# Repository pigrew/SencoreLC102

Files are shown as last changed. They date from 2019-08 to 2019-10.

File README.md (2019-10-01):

# Sencore LC102 Reverse-Engineering

## Firmware

The firmware is stored on an EEPROM. The circuit is designed to only read half of the
ROM, so half of the ROM binary is blank.

It uses a TMP80C39AP processor, part of the Intel MC-48 family. Its ROM is segmented
into four parts (the address bus is only as wide as 1/8th of the EEPROM). It can
toggle output ports in order to switch between I/O segments.

It has been disassembled using the xdasmx software (sadly, not open source), and
also a python script that will merge comments into the disassembly. I've mostly
been working on the "B" part, which handles GPIB.

If browsing the code, you should look at comments in the *.sym files, in adition to 
the *.lsta (annotated source listing) files.

## GPIB/RS232

Stored in firmware part B is the GPIB/RS232 controller logic. It uses an TMP82C43P to
expand its I/O ports and access a GPIB controller IC or UART. Here is the pin mapping that
I've figured out so far:

(From the point of view of LC102. Write goes to IB, Read comes from IB)

| Pin | Function |
|---|---|
| p4.\[3210\]  | D3 .. D0 |
| p5.\[3210\]  | D7 .. D4 |
|------------|----------|
| p6 | Inputs to the 8039 |
| p6.3 | Write ACK (active low) |
| p6.2 | Talk request, (only sent in write mode (P7.0=1)?), clear |
| p6.1 | (Normally low, is this a reset thing?) |
| p6.0 | READ data Available (active low), data already on P4/P5 bus. |
|------------|----------|
| p7 | Outputs from the 8039 |
| p7.3 | |
| p7.2 | W̅R̅I̅T̅E̅  |
| p7.1 | Read complete (active low) |
| p7.0 | Enter LC102 read phase (active low) |

(Below is from the point of view of the meter, not the IB slave)

To initialize:
1. Set p4,p5,p6,p7 to be read ports
2. p7 = 1110 (enter read phase)

To check if I should talk:
1. p7 = 1111
2. Abort if p6.2 is high.
3. Continue with write if p6.2 is low.

To write:

1. Put data on P4/P5 bus
2. Assert p7.2 low
3. Wait until p6.3 goes low (ACK) (p6.2 should go back high at this point, too)
4. Reset p7.2 high

To enter read phase:
1. Set p4/p5/p6 to inputs
2. P7 = 1111
3. p7 = 1110 (Sets read mode)

To perform read:
1. Wait until p6.0 goes low
2. Read data
3. Ack data by asserting p7.1 low
4. Wait until p6.0 goes high
5. Reset p7.1 high

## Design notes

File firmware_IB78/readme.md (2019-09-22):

Firmware for IB78 UART adapter.

|Component| Manufacturer | Part Number |
|---|---|---|
|Micro | Intel |P80C31BH  |
|EPROM |S |27C256-20 FA |
|IO Expander | NEC | D8243C |
|UART | National | NS8250AN/INS8250AN |

Memory map:

| Address | Content |
| --- | --- |
| 0x08 | Baud rate (indexed)
| 0x22 | global status register (bitfield)|
| 0x7fef | Peripheral (only reads), maybe the DIP switches?|
| 0x7ff7 | Peripheral (reads and writes) |
| 0x7ff8 | UART TX/RX data & divisor (muxed by DLAB) |
| 0x7ff9 | UART INT_EN table |
| 0x7ffa | UART INT_FLAG table |
| 0x7ffb | UART line control (parity, stop bits, etc) |
| 0x7ffc | UART modem control |
| 0x7ffd | UART line status |
| 0x7ffe | UART modem status |

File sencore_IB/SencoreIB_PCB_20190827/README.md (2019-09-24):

# Sencore-IB to USB PCB

This is an Altium-based PCB project for a Sencore-IB to USB clone.

# Defects

Some defects have been noticed on this PCB revision:

1. The selected isolated DC-DC converter is unregulated. This would fry the bus tranceiver IC. Correct by cutting the track at the input of the bus tranceiver IC and add a TPS77050 LDO.
2. Some silkscreens are not in the proper place. A lot of the pin-1 designators didn't make it.
3. The selected STM32F042 barely has enough RAM to run the USB stack. Board revisions need a different footprint to accept MCUs with more RAM. For the current footprint, STM32F070F6P6TR could be used which has more flash, but not more RAM (and it needs an external crystal).
4. USB D+ and D- are swapped; Do a crossover in place of R17/R18.
5. Pinout of U3 is flipped; Mount part upsidedown, but leave the pin closest to the RS232 connector up in the air (the flag pin).
6. JTAG pins are connected to the wrong place. SWDIO should be pin13, SWCLK should be pin14

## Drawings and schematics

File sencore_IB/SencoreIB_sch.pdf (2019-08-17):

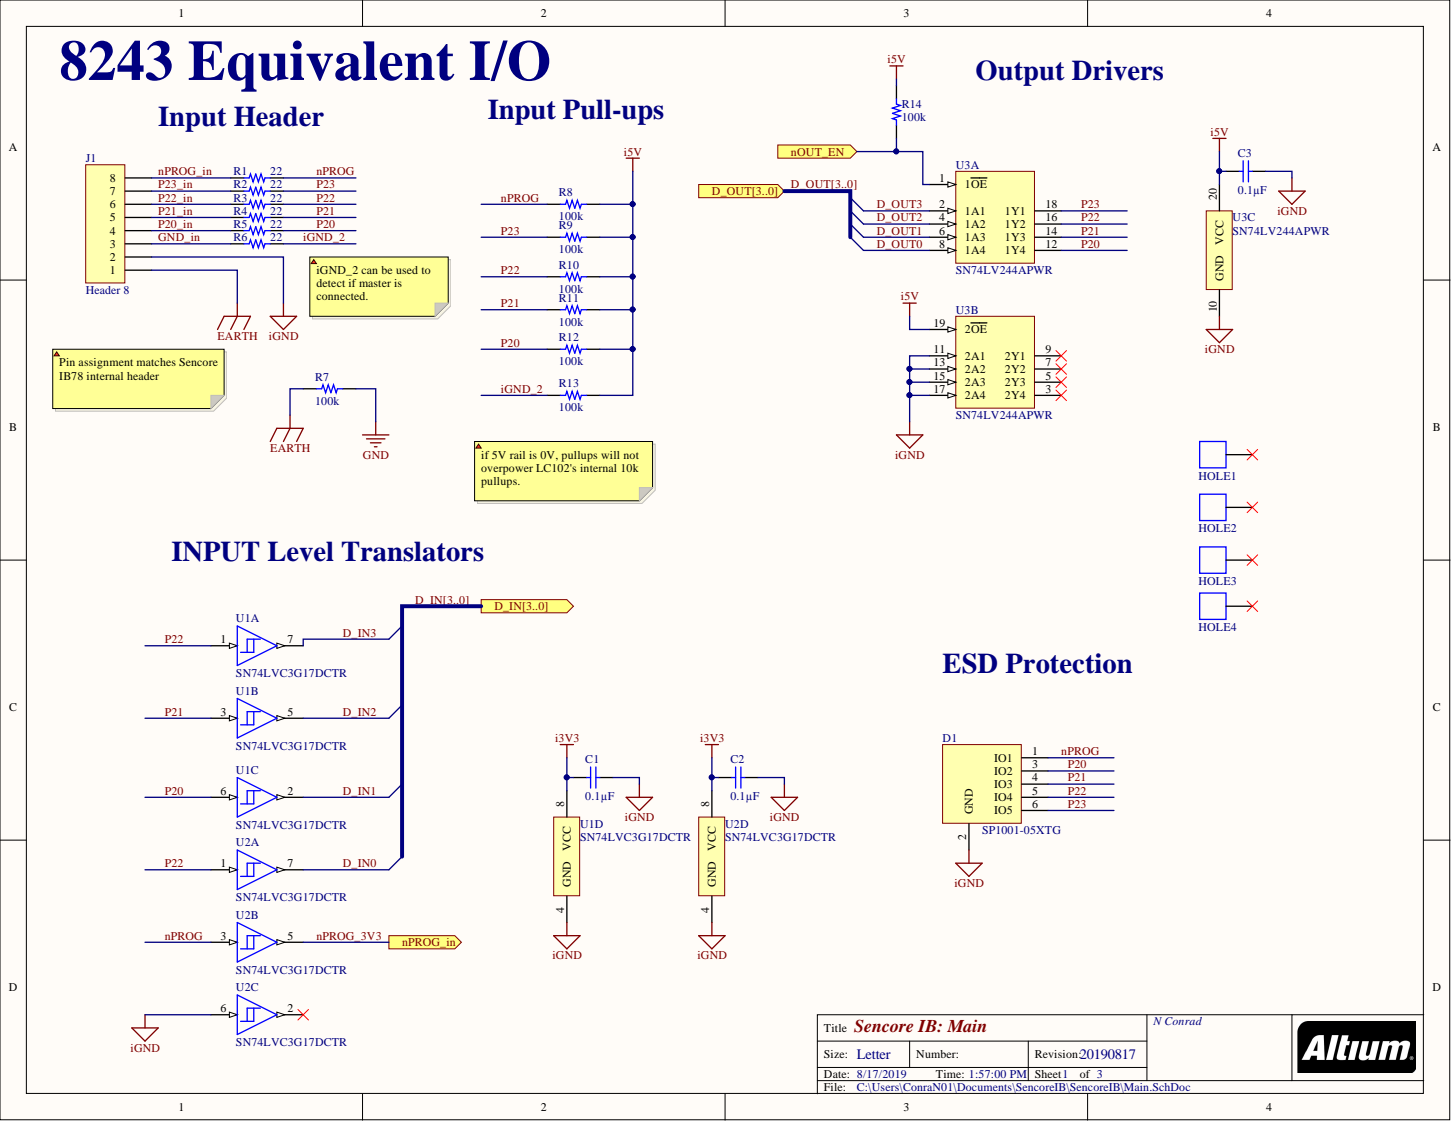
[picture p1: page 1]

iGND_2 can be used to
detect if master is
connected.

Pin assignment matches Sencore
IB78 internal header

if 5V rail is 0V, pullups will not
overpower LC102's internal 10k
pullups.

Sencore IB: Main Title | N Conrad

Size: Letter | Number: | Revision:
Date: 8/17/2019 Time: 1:57:00 PM | | Sheet of

C:\Users\ConraN01\Documents\SencoreIB\SencoreIB\Main.SchDoc

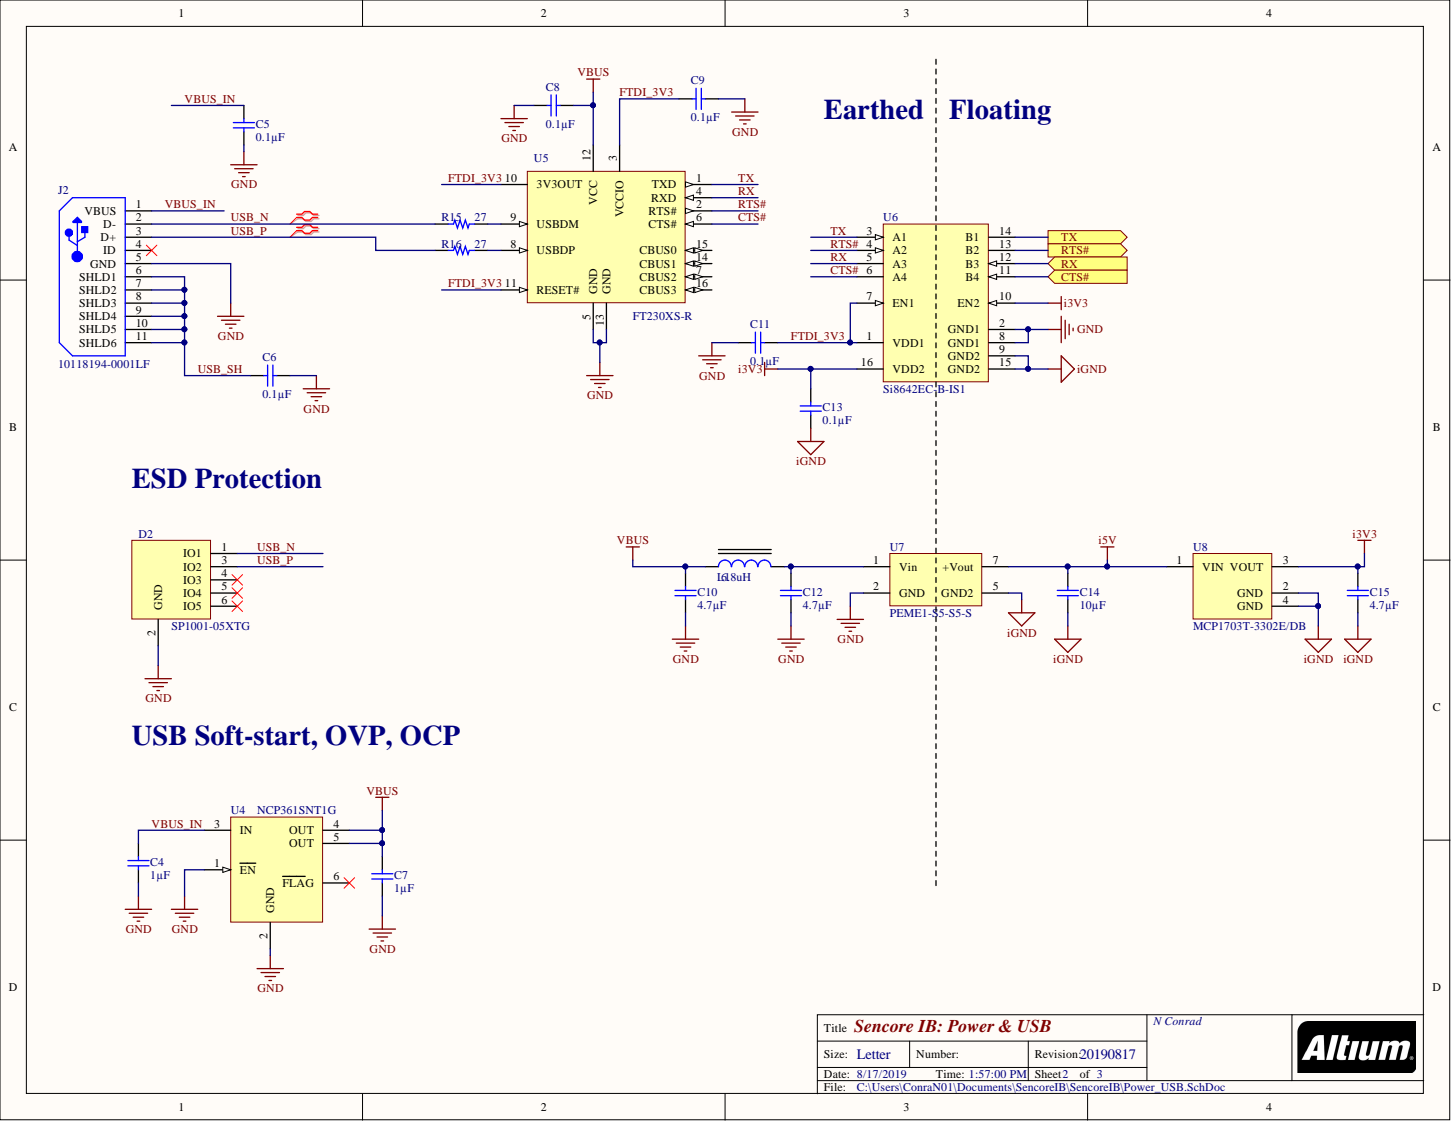
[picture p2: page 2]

GND
USB Soft-start, OVP, OCP

Sencore IB: Power & USB

C:\Users\ConraN01\Documents\SencoreIB\SencoreIB\Power_USB.SchDoc

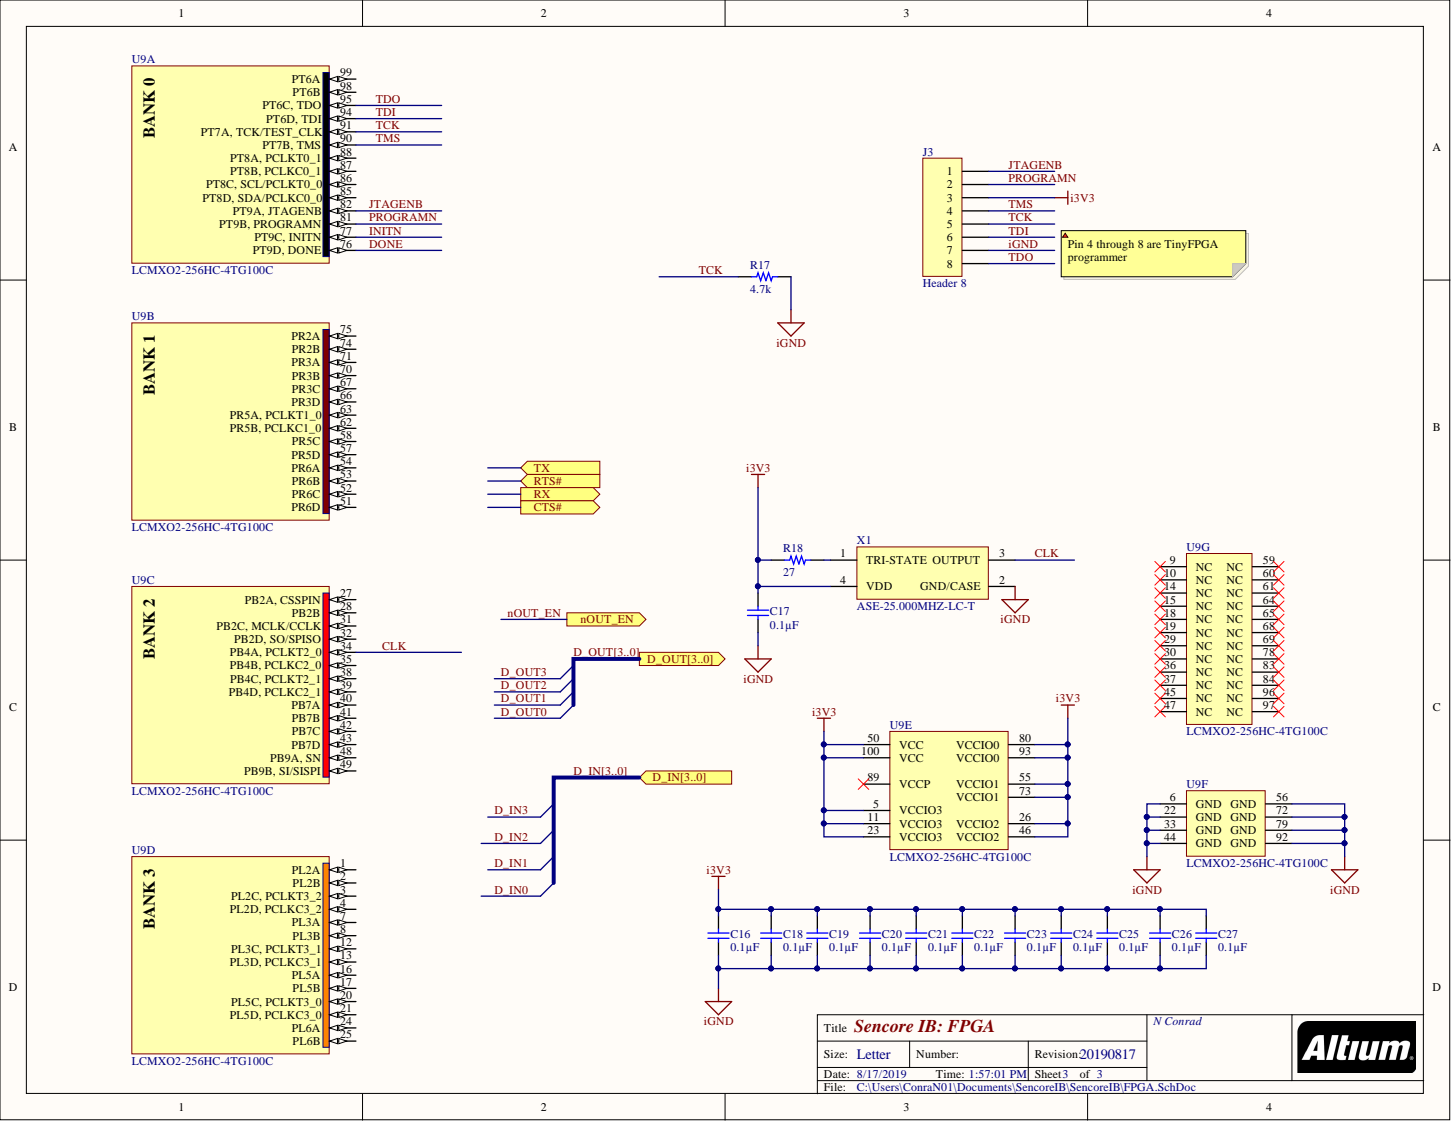
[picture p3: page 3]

Pin 4 through 8 are TinyFPGA
programmer

C:\Users\ConraN01\Documents\SencoreIB\SencoreIB\FPGA.SchDoc

Line # | Description | Designator | Q uantity | TargetPrice | Manufacturer1 | ManufacturerPart Number1 | Supplier 1 | SupplierPart Number1 | Supplier Unit Price 1 | SupplierSubtotal 1
1 | C A P C ER 0.1UF 50V X7R 0603 | C 1-C 3,C 5,C 6, | 21 | 0.21 | Murata | GC J188R71H104KA12D | Digi-Key | 490-5798-1-ND | 0.21 | 4.41
2 | C A P C ER 1UF 25V X7R 0603 | C 4,C7 | 2 | 0.31 | Murata | GC M188R71E105KA64D | Digi-Key | 490-10673-1-ND | 0.31 | 0.62
3 | C A P C ER 4.7UF 25V X7S 0805 | C 10,C 12,C15 | 3 | 0.49 | Murata | GC M21BC 71E475KE36L | Digi-Key | 490-14435-1-ND | 0.49 | 1.47
4 | C A P C ER 10UF 10V X7R 0805 | C14 | 1 | 0.62 | Murata | GC M21BR71A106KE22K | Digi-Key | 490-14531-1-ND | 0.62 | 0.62
5 | TV S DIO DE 5.5VWM 13VC SOT563 | D1,D2 | 2 | 0.6 | Littelfuse | SP1001-05XTG | Digi-Key | F 2898CT-ND | 0.6 | 1.2
6 | Header, 8-Pin | J1, J3 | 2 | 0
7 | MicroUSB B Ty peReceptacle, 1.8 A ,-55 toJ 2 | | 1 | 0.42 | A mphenol FCI | 10118194-0001LF | Digi-Key | 609-4618-6-ND | 0.42 | 0.42
8 | F IXED IND 6.8UH 1.45A 117.6 MOHM | L1 | 1 | 0.29 | TaiyoYuden | NRS4018T6R8MDGJ | Digi-Key | 587-2894-1-ND | 0.29 | 0.29
9 | RES SMD 22 O HM 5% 1/10W0603 | R1-R6 | 6 | 0.02 | Yageo | RC 0603JR-0722RL | Digi-Key | 311-22GRCT-ND | 0.02 | 0.2
10 | RES SMD 100KO HM 5% 1/10W0603 | R7-R14 | 8 | 0.02 | Yageo | RC 0603JR-07100KL | Digi-Key | 311-100KGRCT-ND | 0.02 | 0.2
11 | RES SMD 27 O HM 5% 1/10W0603 | R15,R16,R18 | 3 | 0.02 | Yageo | RC 0603JR-0727RL | Digi-Key | 311-27GRCT-ND | 0.02 | 0.2
12 | RES SMD 4.7K O HM 5% 1/10W0603 | R17 | 1 | 0.1 | Yageo | RC 0603JR-074K7L | Digi-Key | 311-4.7KGRCT-ND | 0.1 | 0.1
13 | TRIPLE SC HMITT-TRIGGERBUFFER,DCU1, U2 | | 2 | 0.69 | Texas InstrumentsSN74LVC3G17DCTR | | Mouser | 595-SN74LVC3G17DCTR | 0.69 | 1.38
14 | O ctal Buffers/Drivers With 3-StateO utputs,U3 | | 1 | 0.46546 | Texas InstrumentsSN74LV 244APWR | | F arnell | 1619139 | 0.46546 | 0.46546
15 | IC USB POS OVP/OCP 5TSOP | U4 | 1 | 0.73 | O N SemiconductorNC P361SNT1G | | Digi-Key | NC P361SNT1GOSCT-ND | 0.73 | 0.73
16 | USB toBasicUA RT InterfaceC hip,UHC I/U5 | | 1 | 1.96 | FTDI | FT230X S- R | F arne ll | 2081321 | 1.96 | 1.96
17 | Low-PowerQ uad-C hannel Digital IsolatorU 6 | | 1 | 3.09 | Silico n Labs | S I8642E C-B-IS1 | Digi-Key | 336-2094-5-ND | 3.09 | 3.09
18 | 5 V dc, 0.2 A , 1 W, 4.5 ~ 5.5 V dc Input Ra U7 | | 1 | 0.29 | TaiyoYuden | NRS4018T6R8MDGJ | Digi-Key | 587-2894-1-ND | 0.29 | 0.29
19 | 250 mA , 16V, Low Q uiescent C urrent LDO U8 | | 1 | 0.64 | Micr ochip | MC P1703T-3302E/DB | Digi-Key | MC P1703T-3302E/DBDKR | 0.64 | 0.64
20 | MachXO 2 High PerformanceC PLD with 256 U9 | | 1 | 4. 29 | L atticeSem iconduc LCMXO2-256HC-4TG1 00C | | Mouse r | 842-2256HC4TG100C | 4.29 | 4.29
21 | C MO S C ry stal O scillatorl,3.3 V , 25 MHz,+X1 | | 1 | 1.09 | Abracon | A SE-25.000MHZ-LC-T | Newark | 84R2104 | 1.09 | 1.09

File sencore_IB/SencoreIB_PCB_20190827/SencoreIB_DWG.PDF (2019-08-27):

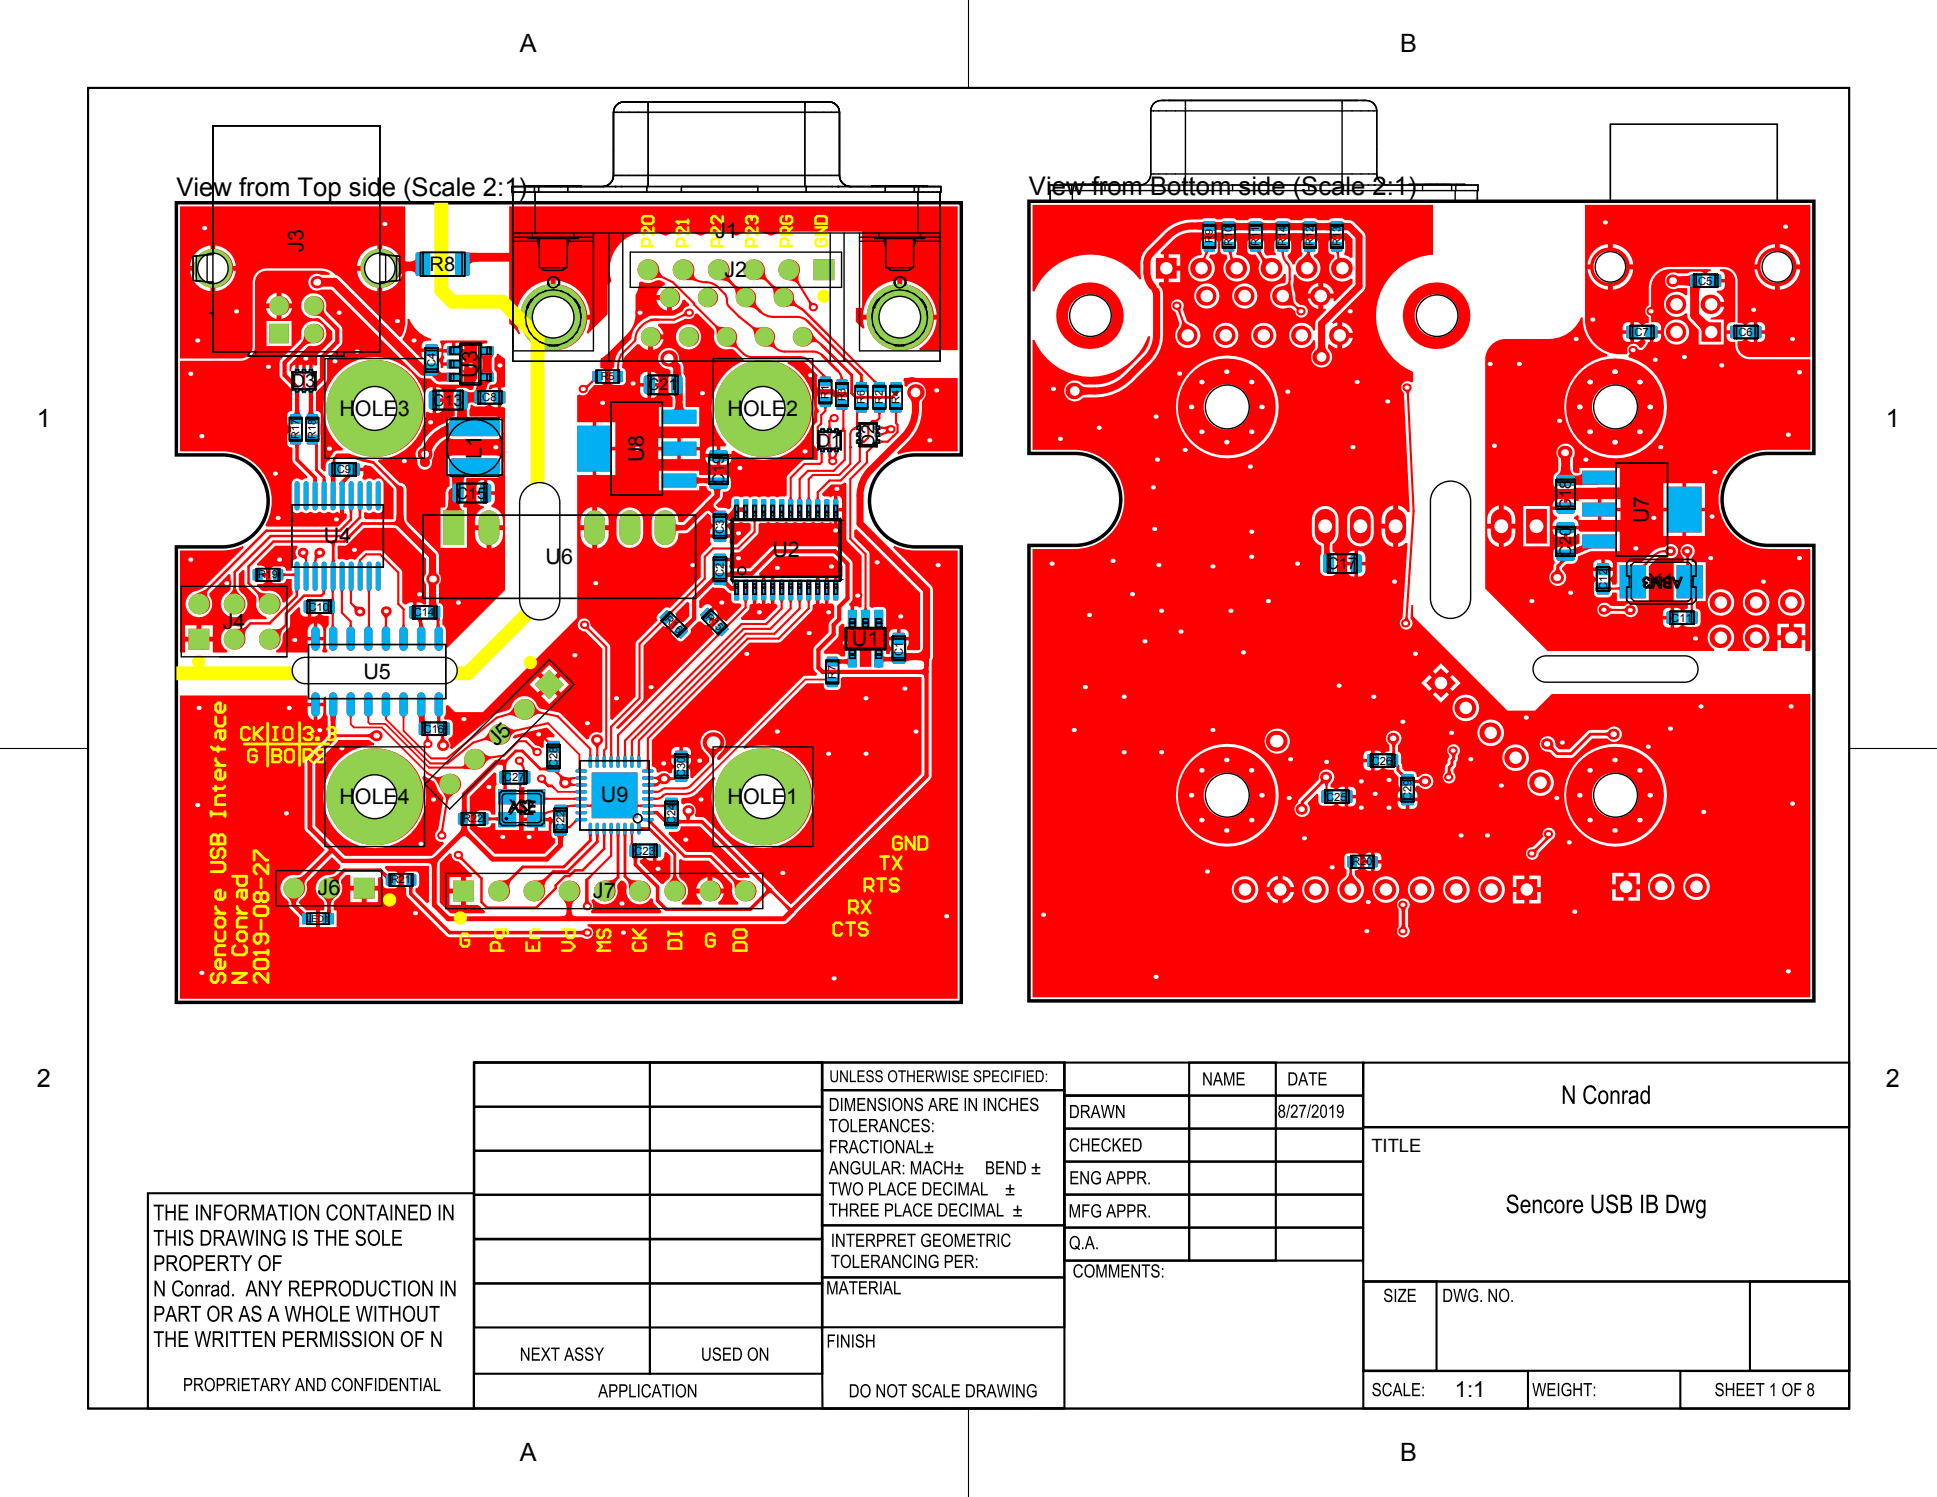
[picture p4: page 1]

View from Top side (Scale 2:1)

View from Bottom side (Scale 2:1)

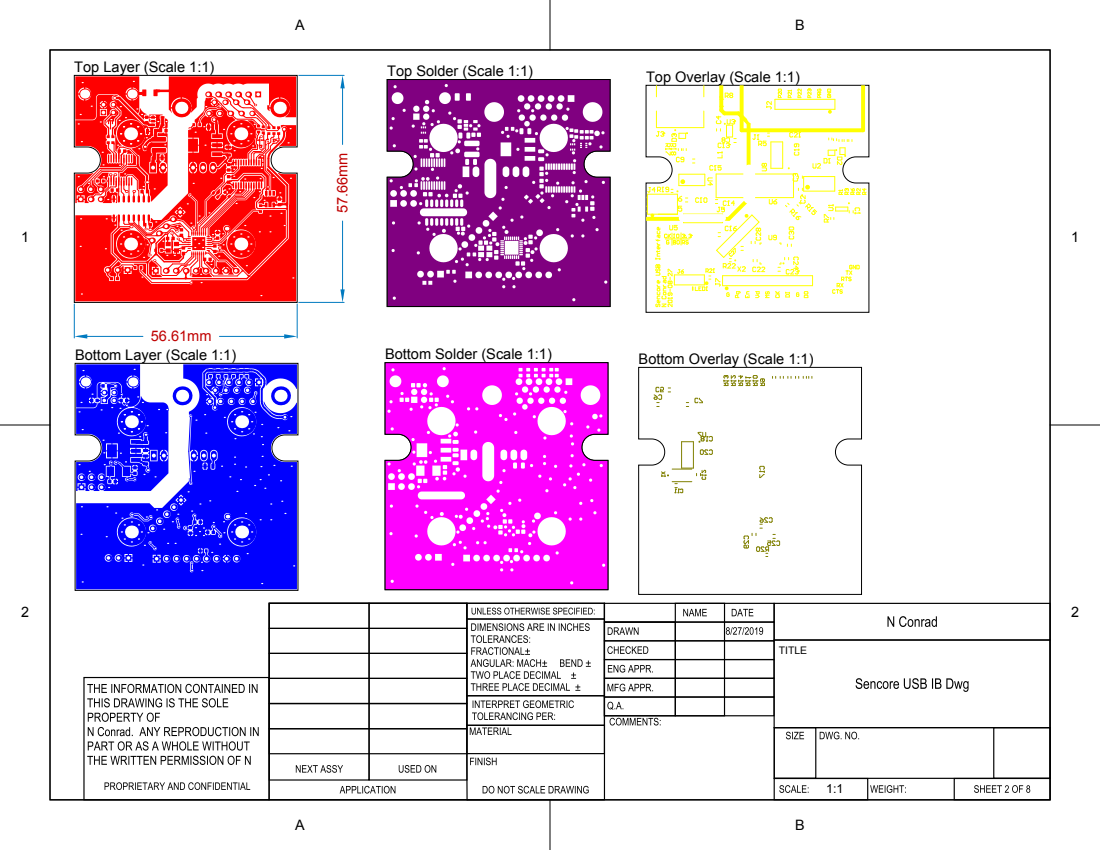
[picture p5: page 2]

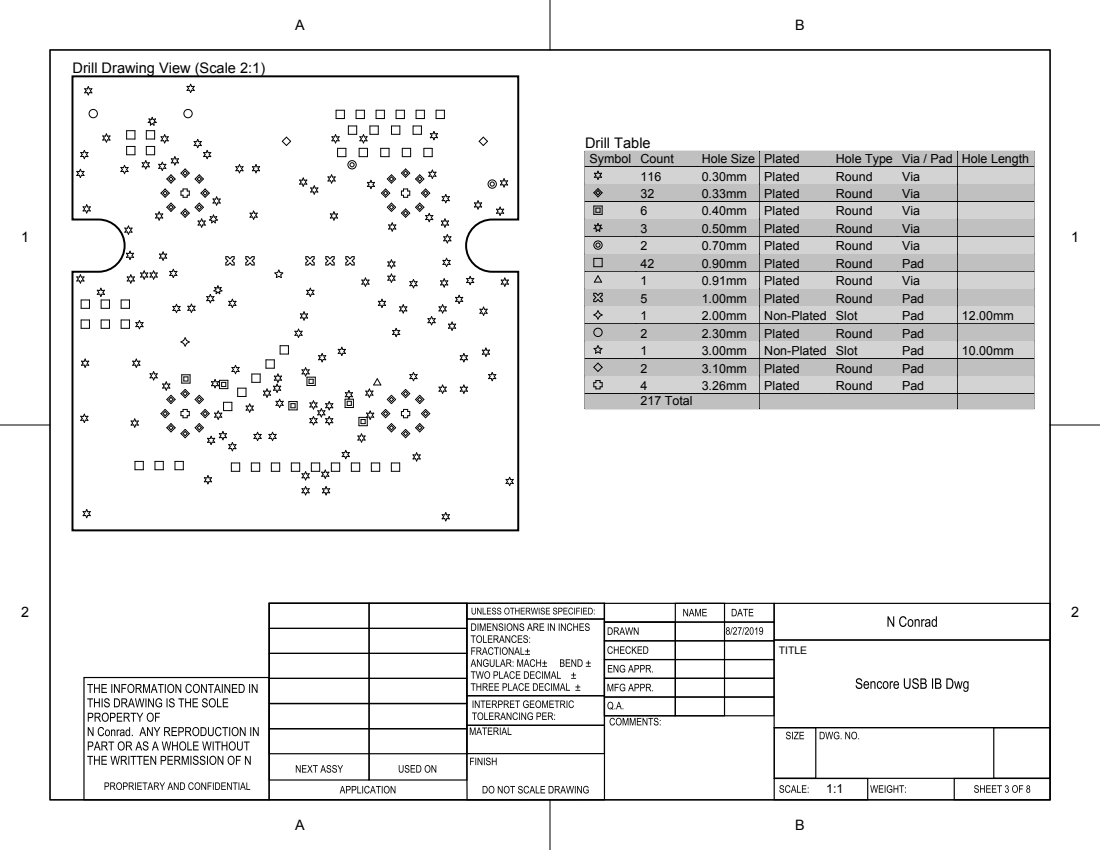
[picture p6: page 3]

Drill Drawing View (Scale 2:1)

Symbol | Count | Hole Size | Plated | Hole Type | Via / Pad | Hole Length

116 | 0.30mm | Plated | Round | Via
32 | 0.33mm | Plated | Round | Via
6 | 0.40mm | Plated | Round | Via
3 | 0.50mm | Plated | Round | Via
2 | 0.70mm | Plated | Round | Via
42 | 0.90mm | Plated | Round | Pad
1 | 0.91mm | Plated | Round | Via
5 | 1.00mm | Plated | Round | Pad
1 | 2.00mm | Non-Plated | Slot | Pad | 12.00mm
2 | 2.30mm | Plated | Round | Pad
1 | 3.00mm | Non-Plated | Slot | Pad | 10.00mm
2 | 3.10mm | Plated | Round | Pad
4 | 3.26mm | Plated | Round | Pad
217 Total

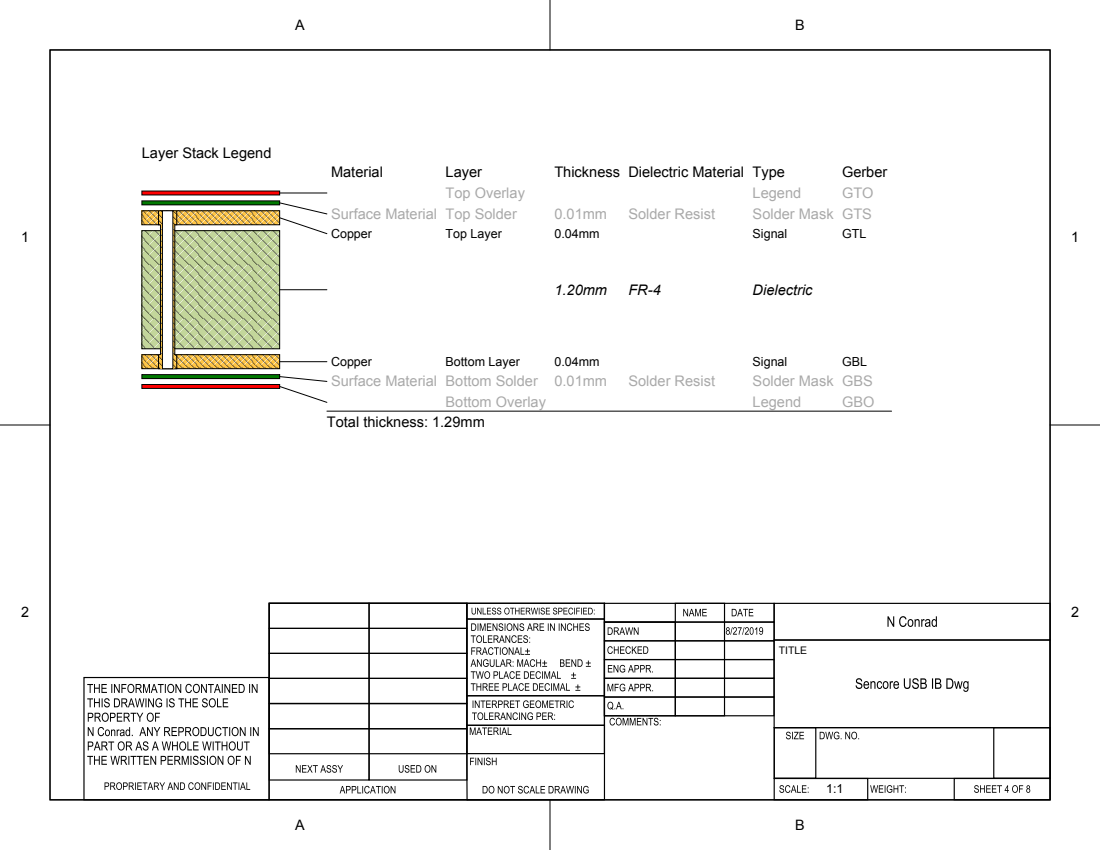
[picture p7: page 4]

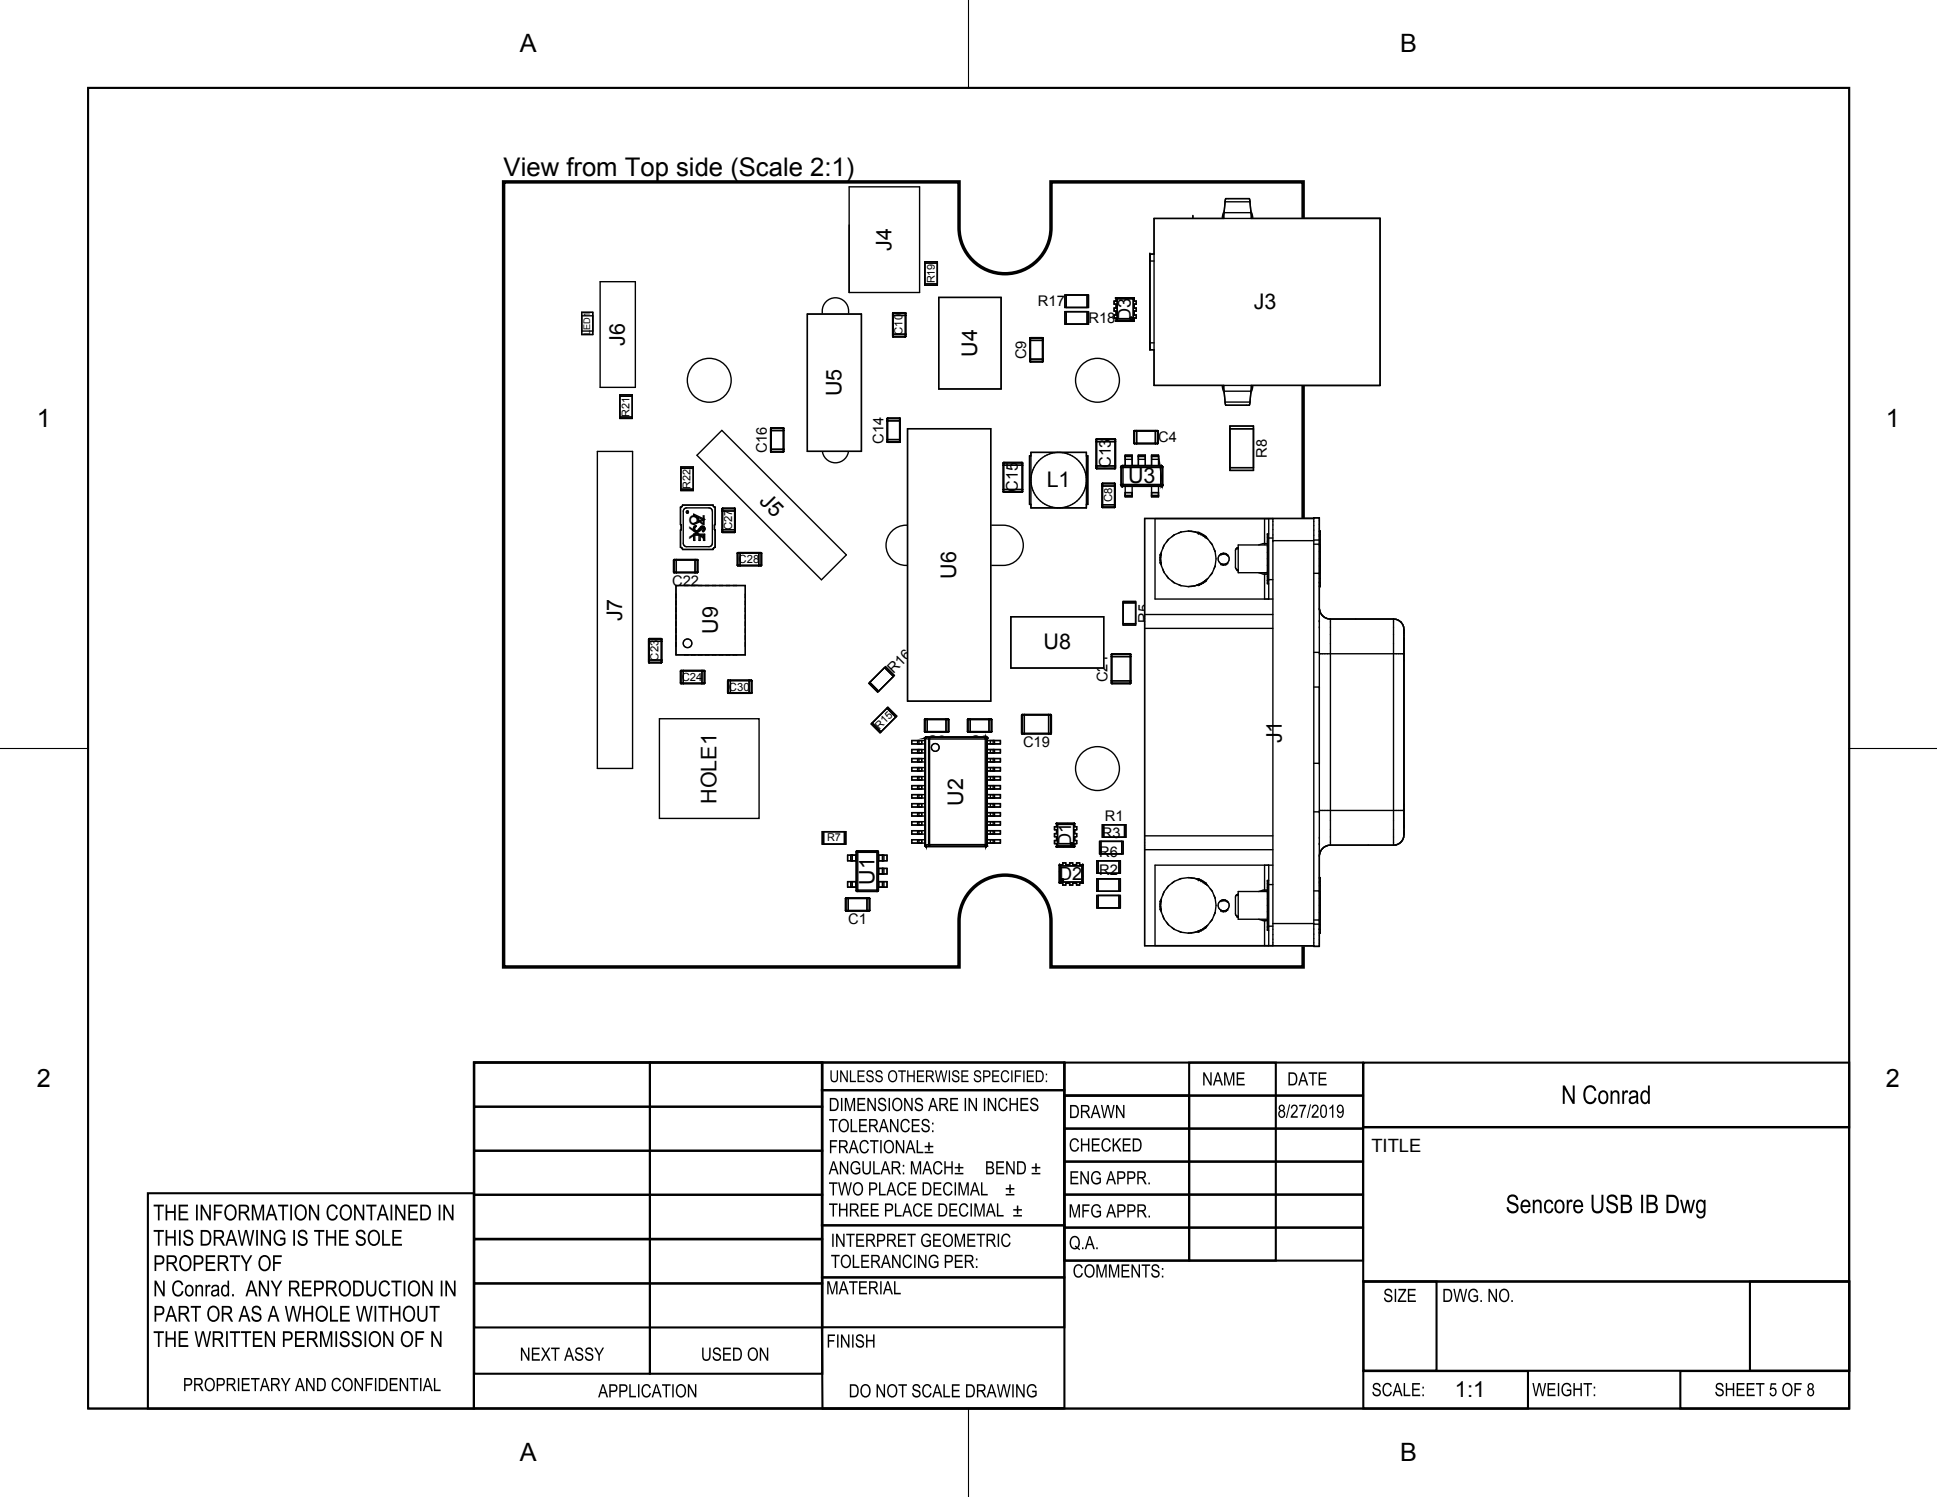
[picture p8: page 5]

View from Top side (Scale 2:1)

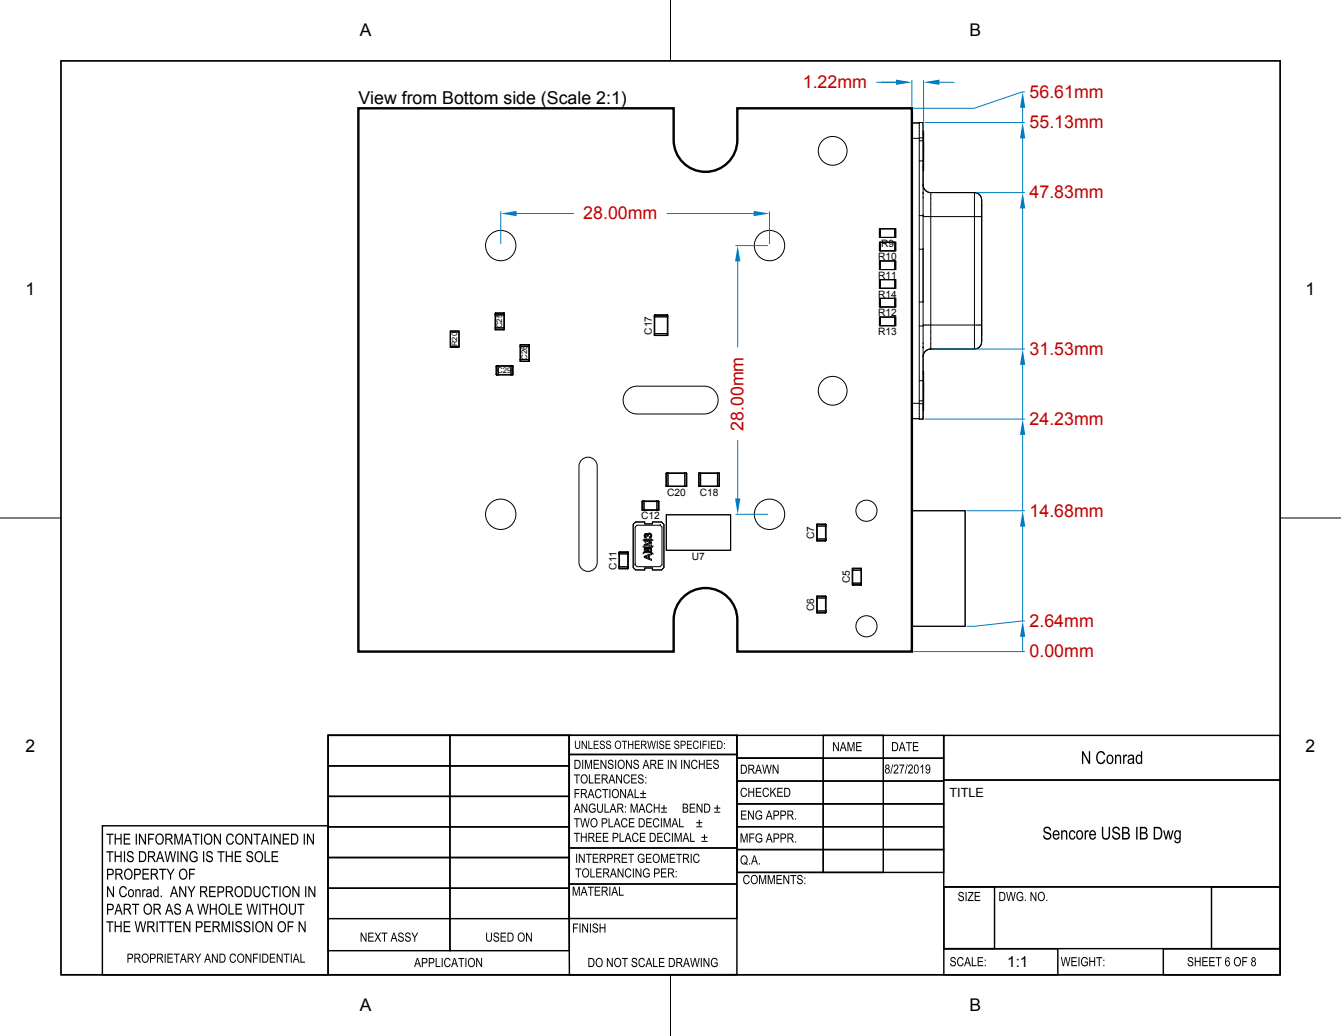
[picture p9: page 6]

View from Bottom side (Scale 2:1)

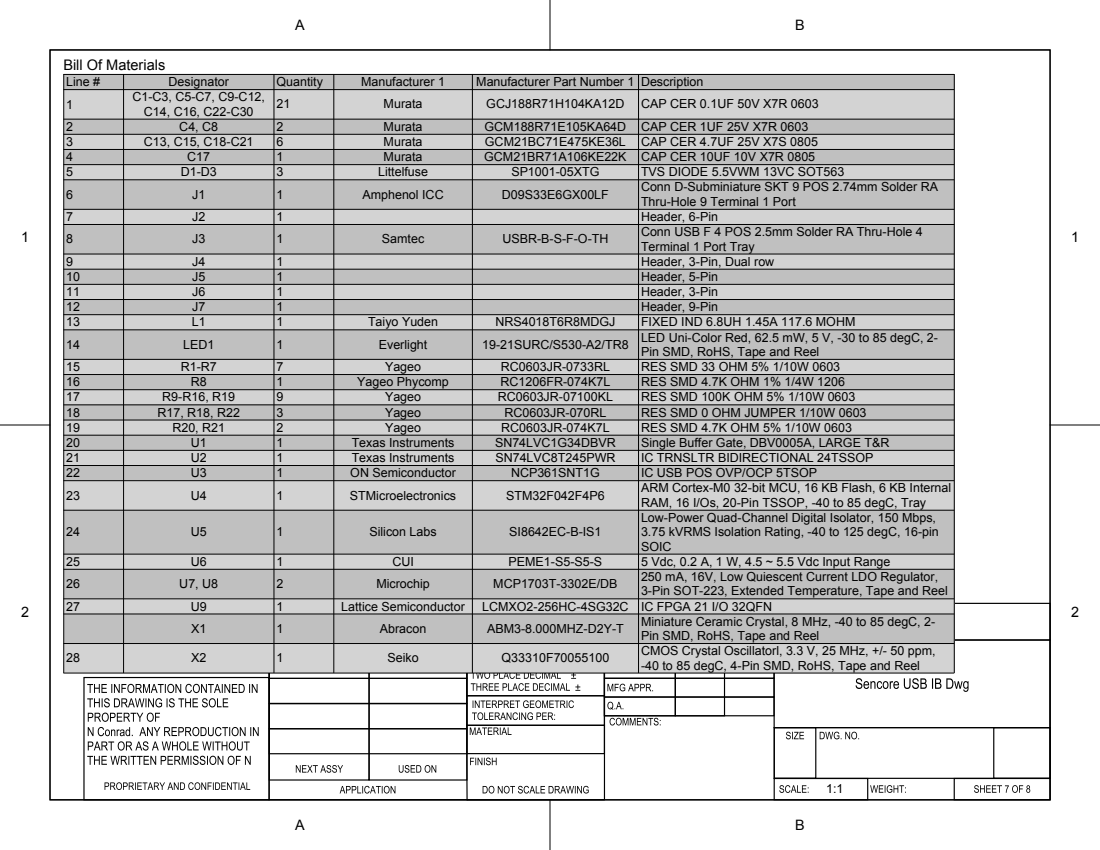
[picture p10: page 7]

Line # | Designator | Quantity | Manufacturer 1 | Manufacturer Part Number 1 | Description
1 | C1-C3, C5-C7, C9-C12, C14, C16, C22-C30 | 21 | Murata | GCJ188R71H104KA12D | CAP CER 0.1UF 50V X7R 0603

2 | C4, C8 | 2 | Murata | GCM188R71E105KA64D | CAP CER 1UF 25V X7R 0603
3 | C13, C15, C18-C21 | 6 | Murata | GCM21BC71E475KE36L | CAP CER 4.7UF 25V X7S 0805
4 | C17 | 1 | Murata | GCM21BR71A106KE22K | CAP CER 10UF 10V X7R 0805
5 | D1-D3 | 3 | Littelfuse | SP1001-05XTG | TVS DIODE 5.5VWM 13VC SOT563
6 | J1 | 1 | Amphenol ICC | D09S33E6GX00LF | Conn D-Subminiature SKT 9 POS 2.74mm Solder RA Thru-Hole 9 Terminal 1 Port

7 | J2 | 1 | | | Header, 6-Pin
8 | J3 | 1 | Samtec | USBR-B-S-F-O-TH | Conn USB F 4 POS 2.5mm Solder RA Thru-Hole 4 Terminal 1 Port Tray

9 | J4 | 1 | | | Header, 3-Pin, Dual row
10 | J5 | 1 | | | Header, 5-Pin
11 | J6 | 1 | | | Header, 3-Pin
12 | J7 | 1 | | | Header, 9-Pin
13 | L1 | 1 | Taiyo Yuden | NRS4018T6R8MDGJ | FIXED IND 6.8UH 1.45A 117.6 MOHM
14 | LED1 | 1 | Everlight | 19-21SURC/S530-A2/TR8 | LED Uni-Color Red, 62.5 mW, 5 V, -30 to 85 degC, 2-Pin SMD, RoHS, Tape and Reel

15 | R1-R7 | 7 | Yageo | RC0603JR-0733RL | RES SMD 33 OHM 5% 1/10W 0603
16 | R8 | 1 | Yageo Phycomp | RC1206FR-074K7L | RES SMD 4.7K OHM 1% 1/4W 1206
17 | R9-R16, R19 | 9 | Yageo | RC0603JR-07100KL | RES SMD 100K OHM 5% 1/10W 0603
18 | R17, R18, R22 | 3 | Yageo | RC0603JR-070RL | RES SMD 0 OHM JUMPER 1/10W 0603
19 | R20, R21 | 2 | Yageo | RC0603JR-074K7L | RES SMD 4.7K OHM 5% 1/10W 0603
20 | U1 | 1 | Texas Instruments | SN74LVC1G34DBVR | Single Buffer Gate, DBV0005A, LARGE T&R
21 | U2 | 1 | Texas Instruments | SN74LVC8T245PWR | IC TRNSLTR BIDIRECTIONAL 24TSSOP
22 | U3 | 1 | ON Semiconductor | NCP361SNT1G | IC USB POS OVP/OCP 5TSOP
23 | U4 | 1 | STMicroelectronics | STM32F042F4P6 | ARM Cortex-M0 32-bit MCU, 16 KB Flash, 6 KB Internal RAM, 16 I/Os, 20-Pin TSSOP, -40 to 85 degC, Tray

24 | U5 | 1 | Silicon Labs | SI8642EC-B-IS1 | Low-Power Quad-Channel Digital Isolator, 150 Mbps, 3.75 kVRMS Isolation Rating, -40 to 125 degC, 16-pin SOIC

25 | U6 | 1 | CUI | PEME1-S5-S5-S | 5 Vdc, 0.2 A, 1 W, 4.5 ~ 5.5 Vdc Input Range
26 | U7, U8 | 2 | Microchip | MCP1703T-3302E/DB | 250 mA, 16V, Low Quiescent Current LDO Regulator, 3-Pin SOT-223, Extended Temperature, Tape and Reel

1 | Lattice Semiconductor | | LCMXO2-256HC-4SG32C | | IC FPGA 21 I/O 32QFN

X1 | 1 | | Abracon | | Miniature Ceramic Crystal, 8 MHz, -40 to 85 degC, 2-

ABM3-8.000MHZ-D2Y-T | | Pin SMD, RoHS, Tape and Reel

28 | X2 | | Q33310F70055100 | CMOS Crystal Oscillatorl, 3.3 V, 25 MHz, +/- 50 ppm, -40 to 85 degC, 4-Pin SMD, RoHS, Tape and Reel | TITLE

1 | Seiko

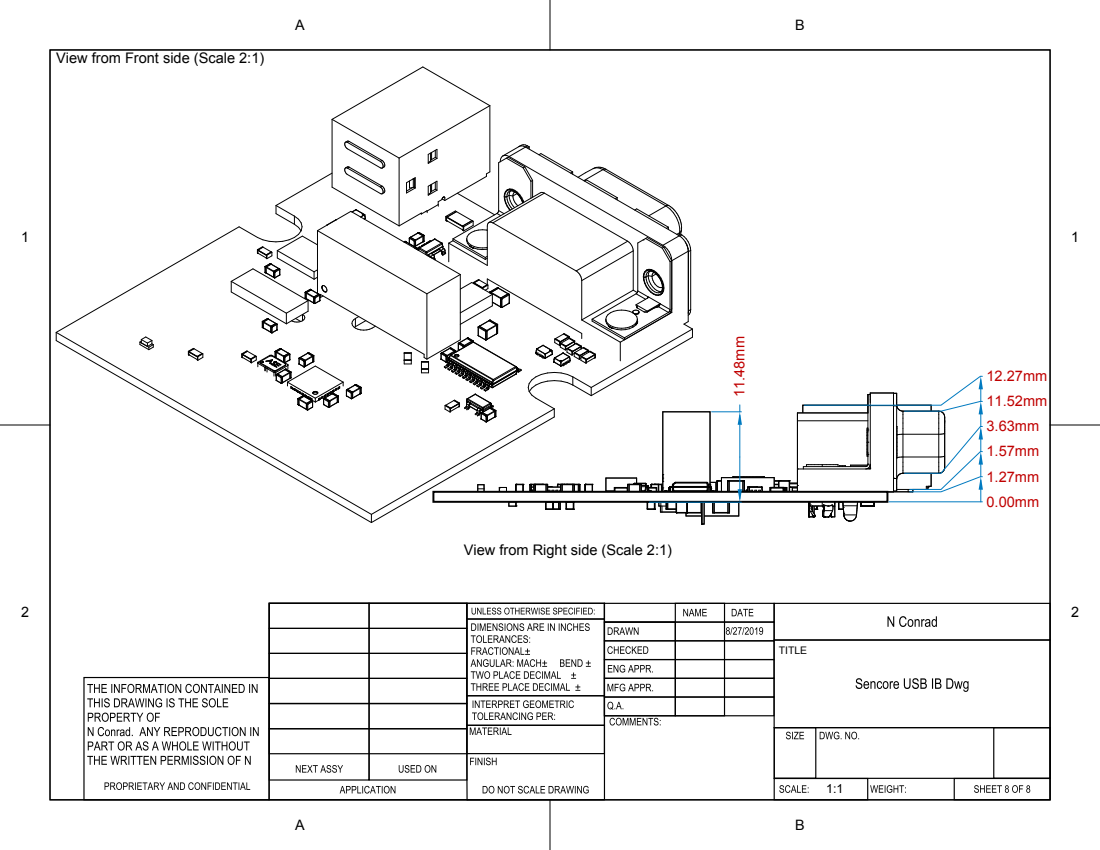
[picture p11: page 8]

View from Front side (Scale 2:1)

View from Right side (Scale 2:1)

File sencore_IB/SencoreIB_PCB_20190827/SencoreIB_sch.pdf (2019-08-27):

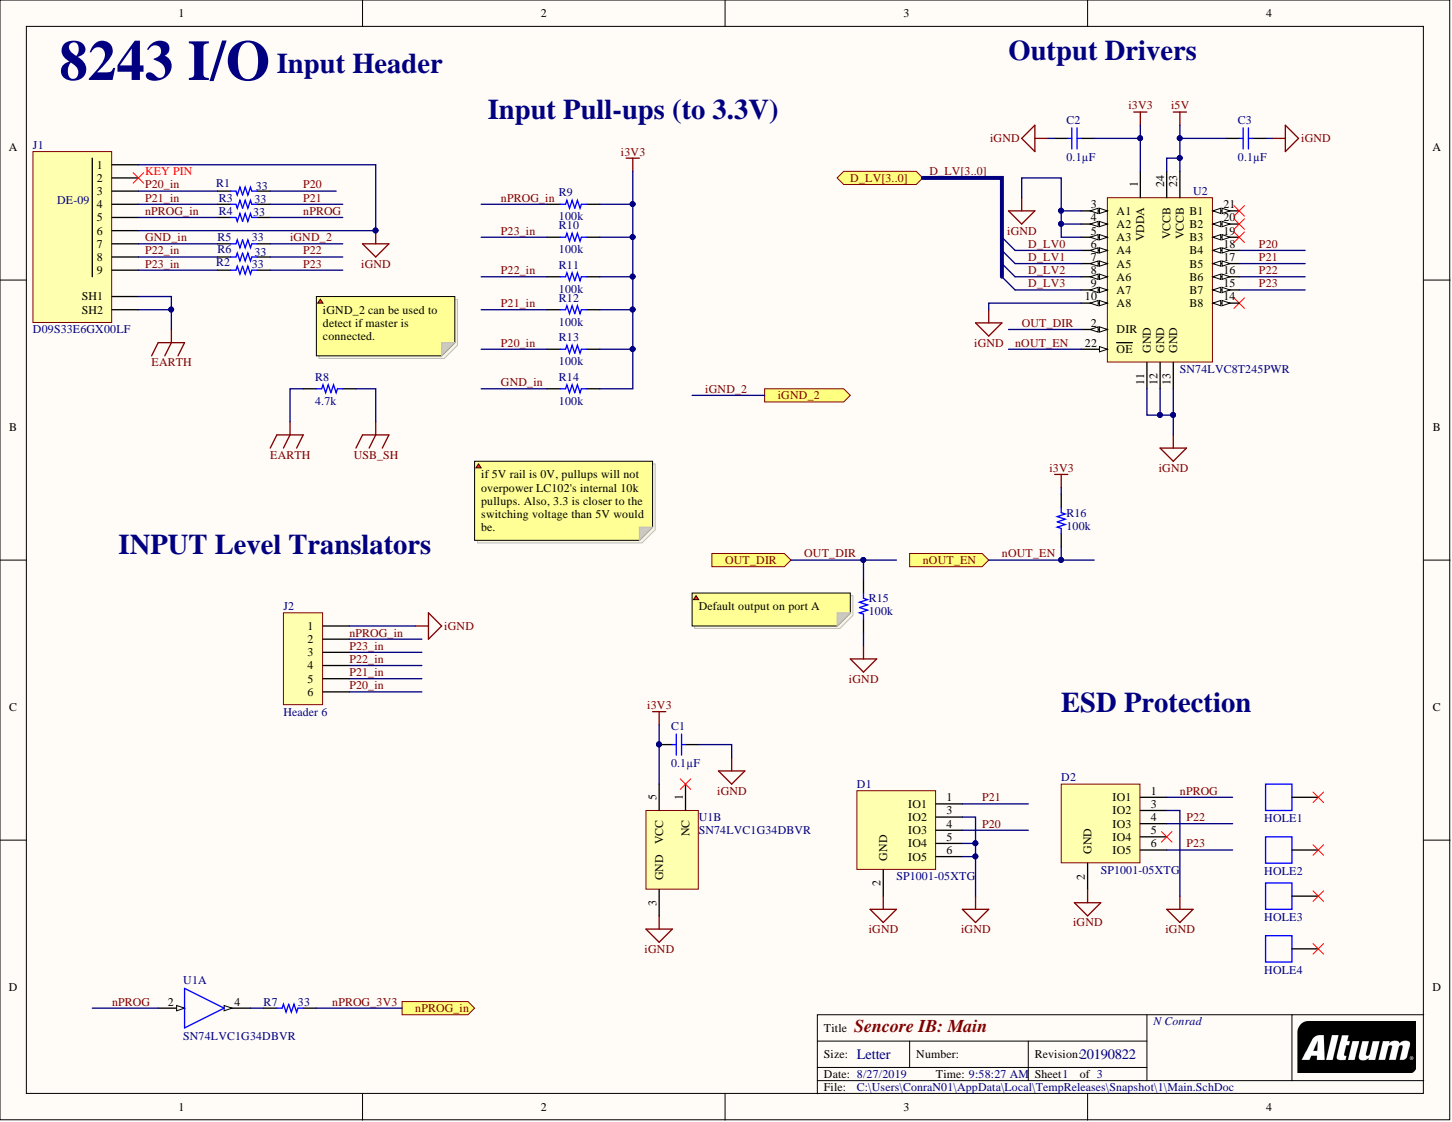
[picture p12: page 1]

Input Pull-ups (to 3.3V)

iGND_2 can be used to
detect if master is
connected.

if 5V rail is 0V, pullups will not
overpower LC102's internal 10k
pullups. Also, 3.3 is closer to the
switching voltage than 5V would

Default output on port A

Sencore IB: Main Title | N Conrad

Size: Letter | Number: | Revision:
Date: 8/27/2019 Time: 9:58:27 AM | | Sheet of

C:\Users\ConraN01\AppData\Local\TempReleases\Snapshot\1\Main.SchDoc


GND
USB Soft-start, OVP, OCP

Sencore IB: Power & USB | N Conrad

Letter

C:\Users\ConraN01\AppData\Local\TempReleases\Snapshot\1\Power_USB.SchDoc


DONE should be normally usable. Worst
case, it's open drain, so shouldn't
conflict...

Pin 5 through 9 are TinyFPGA
programmer "compatible"

C:\Users\ConraN01\AppData\Local\TempReleases\Snapshot\1\FPGA.SchDoc

Line # | Description | Designator | Q uantity | Manufacturer 1 | Manufacturer Part Number 1 | Supplier 1 | Supplier Part Number 1 | Supplier Unit Price 1 | Supplier Subtotal 1
1 | C A P C ER 0.1UF 50V X7R 0603 | C 1-C 3, C 5-C 7, C 9-C 12, C 14 | 21 | Murata | GC J188R71H104KA12D | Digi-Key | 490-5798-1-ND | 0.21 | 4.41
2 | C A P C ER 1UF 25V X7R 0603 | C 4, C8 | 2 | Murata | GC M188R71E105KA64D | Digi-Key | 490-10673-1-ND | 0.31 | 0.62
3 | C A P C ER 4.7UF 25V X7S 0805 | C 13, C 15, C 18-C21 | 6 | Murata | GC M21BC 71E475KE36L | Digi-Key | 490-14435-1-ND | 0.49 | 2.94
4 | C A P C ER 10UF 10V X7R 0805 | C17 | 1 | Murata | GC M21BR71A106KE22K | Digi-Key | 490-14531-1-ND | 0.62 | 0.62
5 | TV S DIO DE 5.5VWM 13VC SOT563 | D1-D3 | 3 | Littelfuse | SP1001-05XTG | Digi-Key | F 2898CT-ND | 0.6 | 1.8
6 | C onn D-Subminiature SKT 9 PO S 2.74mmJ1 | | 1 | A mphenol ICC | D09S33E6GX00LF | Digi-Key | 609-6160-ND | 1.43 | 1.43
7 | Header, 6-Pin | J2 | 1
8 | C onn USB F 4 PO S 2.5mm Solder RA ThrJ3 | | 1 | Samtec | USBR-B-S-F-O-TH | Digi-Key | SA M10873-ND | 1.18 | 1.18
9 | Header, 3-Pin, Dual row | J4 | 1
10 | Header, 5-Pin | J5 | 1
11 | Header, 3-Pin | J6 | 1
12 | Header, 9-Pin | J7 | 1
13 | F IXED IND 6.8UH 1.45A 117.6 MOHM | L1 | 1 | Taiyo Yuden | NRS4018T6R8MDGJ | Digi-Key | 587-2894-1-ND | 0.29 | 0.29
14 | LED Uni-C olor Red, 62.5 mW, 5 V , -30 to 85 LED1 | | 1 | Ev erlight | 19-21SURC /S530-A2/TR8
15 | RES SMD 33 O HM 5% 1/10W 0603 | R1-R7 | 7 | Yageo | RC 0603JR-0733RL | Digi-Key | 311-33GRCT-ND | 0.02 | 0.2
16 | RES SMD 4.7K O HM 1% 1/4W 1206 | R8 | 1 | Yageo Phycomp | RC 1206FR-074K7L | Digi-Key | 311-4.70KFRCT-ND | 0.1 | 0.1
17 | RES SMD 100K O HM 5% 1/10W 0603 | R9-R16, R19 | 9 | Yageo | RC 0603JR-07100KL | Digi-Key | 311-100KGRCT-ND | 0.02 | 0.2
18 | RES SMD 0 O HM JUMPER 1/10W 0603 | R17, R18, R22 | 3 | Yageo | RC 0603JR-070RL | Digi-Key | 311-0.0GRCT-ND | 0.022 | 0.22
19 | RES SMD 4.7K O HM 5% 1/10W 0603 | R20, R21 | 2 | Yageo | RC 0603JR-074K7L | Digi-Key | 311-4.7KGRCT-ND | 0.1 | 0.2
20 | Single Buffer Gate, DBV 0005A, LARGE T&U1 | | 1 | Texas InstrumentsSN74LVC1G34DBVR | | Newark | 01J0787 | 0.113 | 0.113
21 | IC TRNSLTR BIDIRECTIONAL 24TSSOP | U2 | 1 | Texas InstrumentsSN74LV C 8T245PWR | | Digi-Key | 296-18593-1-ND | 1.05 | 1.05
22 | IC USB POS OVP/OCP 5TSOP | U3 | 1 | O N SemiconductorNC P361SNT1G | | Digi-Key | NC P361SNT1GOSCT-ND | 0.73 | 0.73
23 | A RM C ortex-M0 32-bit MC U, 16 KB F lash,U 4 | | 1 | STMic roelec tronicsSTM32F 042F4P6 | | F arnell | 2469548 | 2.07 | 2.07
24 | Low-Power Q uad-C hannel Digital IsolatorU 5 | | 1 | Silic on La bs | S I8642E C-B-IS1 | Mouser | 634-SI8642EC-B-IS1 | 3 | 3
25 | 5 V dc, 0.2 A , 1 W, 4.5 ~ 5.5 V dc Input Range U6 | | 1 | CUI | PEME1-S5-S5-S | Digi-Key | 102-6337-ND | 2.29 | 2.29
26 | 250 mA , 16V, Low Q uiescent C urrent LDOU7, U8 | | 2 | Microchip | M C P1703T -3302E/DB | Digi-Key | MC P1703T-3302E/DBDKR | 0.64 | 1.28
27 | IC F PGA 21 I/O 32QFN | U9 | 1 | Lattice SemiconducLCMXO 2-256HC-4SG32C | | Digi-Key | 220-2636-ND | 3.24 | 3.24
| Miniature C eramic C ry stal, 8 MHz, -40 to 85 X1 | | 1 | Abr acon | A BM3-8.000MHZ-D2Y-T | F uture ElectroABM3-8.000MHZ-D2Y-T-C | | 0.67 | 0.67
28 | C MO S C ry stal O scillatorl, 3.3 V , 25 MHz,X2 | | 1 | Seiko | Q33310F 70055100

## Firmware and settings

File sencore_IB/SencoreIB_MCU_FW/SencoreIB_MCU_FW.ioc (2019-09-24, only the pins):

Mcu.UserName=STM32F042F4Px
PA0.Signal=USART2_CTS
PA1.Signal=USART2_RTS
PA11.Signal=USB_DM
PA12.Signal=USB_DP
PA13.Signal=SYS_SWDIO
PA14.Signal=SYS_SWCLK
PA2.Signal=USART2_TX
PA3.Signal=USART2_RX

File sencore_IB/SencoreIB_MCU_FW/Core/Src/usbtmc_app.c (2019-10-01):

/*
 * The MIT License (MIT)
 *
 * Copyright (c) 2019 Nathan Conrad
 *
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
 */

#include <strings.h>
#include <stdlib.h>     /* atoi */
#include "tusb.h"
#include "main.h"
#include "usart.h"

#include "stm32f0xx_it.h"

#if (CFG_USBTMC_CFG_ENABLE_488)
static usbtmc_response_capabilities_488_t const
#else
static usbtmc_response_capabilities_t const
#endif
tud_usbtmc_app_capabilities  =
{
    .USBTMC_status = USBTMC_STATUS_SUCCESS,
    .bcdUSBTMC = USBTMC_VERSION,
    .bmIntfcCapabilities =
    {
        .listenOnly = 0,
        .talkOnly = 0,
        .supportsIndicatorPulse = 0
    },
    .bmDevCapabilities = {
        .canEndBulkInOnTermChar = 0
    },

#if (CFG_USBTMC_CFG_ENABLE_488)
    .bcdUSB488 = USBTMC_488_VERSION,
    .bmIntfcCapabilities488 =
    {
        .supportsTrigger = 0,
        .supportsREN_GTL_LLO = 0,
        .is488_2 = 0
    },
    .bmDevCapabilities488 =
    {
      .SCPI = 0, ///< Support SCPI command set
      .SR1 = 0,  ///< Supports SRQ (and has interrupt endpoint)
      .RL1 = 0,  ///< Implements 488.2 remote/local state machine
      .DT1 =0,   ///< Has 488.2 Trigger
    }
#endif
};

#define IEEE4882_STB_QUESTIONABLE (0x08u)
#define IEEE4882_STB_MAV          (0x10u)
#define IEEE4882_STB_SER          (0x20u)
#define IEEE4882_STB_SRQ          (0x40u)

static const char idn[] = "Conrad,SencoreIB,SN1,v0.1\r\n";
//static const char idn[] = "TinyUSB,ModelNumber,SerialNumber,FirmwareVer and a bunch of other text to make it longer than a packet, perhaps? lets make it three transfers...\n";
static volatile uint8_t status;

// 0=not query, 1=queried, 2=delay,set(MAV), 3=delay 4=ready?
// (to simulate delay)
static volatile uint16_t queryState = 0;
static volatile uint32_t bulkInStarted;

static size_t buffer_len;
static size_t buffer_tx_ix; // for transmitting using multiple transfers
static uint8_t buffer[225]; // A few packets long should be enough.

static uint8_t uartRxBuffer[225];
static size_t  uartRxBuffer_ix;


static usbtmc_msg_dev_dep_msg_in_header_t rspMsg = {
    .bmTransferAttributes =
    {
      .EOM = 1,
      .UsingTermChar = 0
    }
};

usbtmc_response_capabilities_488_t const * tud_usbtmc_get_capabilities_cb(void) {
	return &tud_usbtmc_app_capabilities;
}

bool tud_usbtmc_msgBulkOut_start_cb(usbtmc_msg_request_dev_dep_out const * msgHeader)
{

  (void)msgHeader;
  buffer_len = 0;
  if(msgHeader->TransferSize > sizeof(buffer))
  {
    return false;
  }
  return true;
}

bool tud_usbtmc_msg_data_cb(void *data, size_t len, bool transfer_complete)
{


	if(len + buffer_len < sizeof(buffer)) {
		memcpy(&(buffer[buffer_len]), data, len);
		buffer_len += len;
	} else {
		tud_usbtmc_start_bus_read();
		return false; // buffer overflow!
	}

	if(transfer_complete && (len >=4) && !strncasecmp("*idn?",data,5)) {
		queryState = 1;
		status |= IEEE4882_STB_MAV;
	} else if(transfer_complete && (len >=4) && !strncasecmp("fetch?",data,6)) {
		queryState = 2;
		status |= IEEE4882_STB_MAV;
	} else if(transfer_complete && (len >=4) && !strncasecmp("len?",data,4)) {
		queryState = 3;
		status |= IEEE4882_STB_MAV;
	} else {
		uart_tx_sync(buffer, buffer_len);
	}

	tud_usbtmc_start_bus_read();
	return true;
}

bool tud_usbtmc_msgBulkIn_complete_cb()
{

  if(queryState != 0) // done
  {
    status &= (uint8_t)~(IEEE4882_STB_MAV); // clear MAV
    queryState = 0;
    bulkInStarted = 0;
    buffer_tx_ix = 0;
  }
  tud_usbtmc_start_bus_read();
  return true;
}

static unsigned int msgReqLen;

bool tud_usbtmc_msgBulkIn_request_cb(usbtmc_msg_request_dev_dep_in const * request)
{


  rspMsg.header.MsgID = request->header.MsgID,
  rspMsg.header.bTag = request->header.bTag,
  rspMsg.header.bTagInverse = request->header.bTagInverse;
  msgReqLen = request->TransferSize;
  bulkInStarted = 1;
  // Always return true indicating not to stall the EP.
  return true;
}

void tud_usbtmc_open_cb(uint8_t interface_id) {
	tud_usbtmc_start_bus_read();
}

void usbtmc_app_task_iter(void) {
	if((queryState == 0) &&  uart_rx_char(&(uartRxBuffer[uartRxBuffer_ix])) ) {
		if(uartRxBuffer[uartRxBuffer_ix] == '\n') {
			  status = (uint8_t)(status | IEEE4882_STB_SRQ); // set SRQ
		}
		uartRxBuffer_ix++;
	}

	if(bulkInStarted && (queryState != 0u)) {
		switch(queryState) {
		case 1:
			tud_usbtmc_transmit_dev_msg_data( idn,  tu_min32(sizeof(idn)-1,msgReqLen),true,false);
			bulkInStarted = 0u;
			break;
		case 2:
			if(uartRxBuffer_ix > 0) {
				tud_usbtmc_transmit_dev_msg_data(uartRxBuffer,  tu_min32(uartRxBuffer_ix,msgReqLen),true,false);
				uartRxBuffer_ix = 0u;
				bulkInStarted = 0u;
			}
			break;
		case 3:
			tud_usbtmc_transmit_dev_msg_data(&uartRxBuffer_ix,  sizeof(uartRxBuffer_ix),true,false);
			bulkInStarted = 0u;
			break;
		}
		// MAV is cleared in the transfer complete callback.
	}
}

bool tud_usbtmc_initiate_clear_cb(uint8_t *tmcResult)
{

  *tmcResult = USBTMC_STATUS_SUCCESS;
  queryState = 0;
  bulkInStarted = false;
  status = 0;
  return true;
}

bool tud_usbtmc_check_clear_cb(usbtmc_get_clear_status_rsp_t *rsp)
{

  queryState = 0;
  bulkInStarted = false;
  status = 0;
  rsp->USBTMC_status = USBTMC_STATUS_SUCCESS;
  rsp->bmClear.BulkInFifoBytes = 0u;
  return true;
}
bool tud_usbtmc_initiate_abort_bulk_in_cb(uint8_t *tmcResult)
{

  bulkInStarted = 0;
  *tmcResult = USBTMC_STATUS_SUCCESS;
  return true;
}
bool tud_usbtmc_check_abort_bulk_in_cb(usbtmc_check_abort_bulk_rsp_t *rsp)
{

  (void)rsp;
  return true;
}

bool tud_usbtmc_initiate_abort_bulk_out_cb(uint8_t *tmcResult)
{
  *tmcResult = USBTMC_STATUS_SUCCESS;
  return true;

}
bool tud_usbtmc_check_abort_bulk_out_cb(usbtmc_check_abort_bulk_rsp_t *rsp)
{
  (void)rsp;
  tud_usbtmc_start_bus_read();
  return true;
}

void tud_usbtmc_bulkIn_clearFeature_cb()
{
}
void tud_usbtmc_bulkOut_clearFeature_cb()
{
  tud_usbtmc_start_bus_read();
}

// Return status byte, but put the transfer result status code in the rspResult argument.
uint8_t tud_usbtmc_get_stb_cb(uint8_t *tmcResult)
{

  uint8_t old_status = status;
  status = (uint8_t)(status & ~(IEEE4882_STB_SRQ)); // clear SRQ

  *tmcResult = USBTMC_STATUS_SUCCESS;
  // Increment status so that we see different results on each read...

  return old_status;
}

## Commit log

2019-08-15 Add capture of LC102 with nothing connected.
    [IB_Notes.xlsx, No_IB.log.csv]
2019-08-17 Add draft of schematics for FPGA-based IB
2019-08-20 Update README.md
    Updates on bus signals based on protocol trace
2019-08-27 Add IB PCB data.
    [FPGA.SchDoc, Main.SchDoc, Power_USB.SchDoc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]
2019-08-29 Use tri-state output for p2 data, and remove the (old) p2_oe wire, to later be replaced with p2_dir.
    Assign some IO pins.
2019-08-29 Set clock to 8 MHz, and UART to 125 kHz.
2019-08-29 Implement IO level converter in the testbench (and create direction output pin).
2019-08-29 Latch the LED output for a few ms.
2019-08-29 Set p2_buf_dir pin.
2019-08-29 Provide updated notes on PCB.
    [FPGA.SchDoc, Main.SchDoc, Power_USB.SchDoc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]
2019-08-30 Assign gnd2 input pin.
2019-09-01 Update README.md
    More notes on PCB corrections
2019-09-05 Update README.md
    More board issues.
2019-09-24 Boost baud rate, some FPGA fixes.
    [SencoreIB_MCU_FW.ioc]
